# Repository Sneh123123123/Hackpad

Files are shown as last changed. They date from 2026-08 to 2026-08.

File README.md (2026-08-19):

# Hackpad / Macropad

A compact, USB-programmable custom hackpad using the Seeed Studio XIAO MCU. This device features a 4-button layout, a rotary potentiometer, an OLED graphic display and an audio module for tactile, multimedia, and automation control.

## Hardware Specifications

- **Microcontroller:** Seeed Studio XIAO (SAMD21)
- **Components:** 
  - 4 x Buttons
  - 1 x Rotary Potentiometer 
  - 1 x Audio Module
  - 1x OLED Graphic Display

## Core Features

- **Macropad Buttons:** 4 programmable buttons mapped to keyboard shortcuts, app launches, or dev tools (or whatever you want). 
- **Rotary Potentiometer:** Rotary potentiometer for smooth scrolling, volume control, or brush resizing.
- **Audio Module:** Audio module for status chimes, error beeps, or cool sound effects.
- **Pocket-Sized:** Minimalistic layout using the ultra-small Seeed Studio XIAO footprint.
- **OLED Graphic Display:** A Graphic Display for cool illustrations, animations and displays.

## Software & Firmware Setup

### Preparation
1. Download and install the [Arduino IDE](https://arduino.cc).
2. Add Seeed Studio boards to your IDE manager using the official guide.

### Installation
1. **Clone this repository:**
   (Yet to Add)
2. **Open the project:** Launch Arduino IDE and open `...`.
3. **Select Board:** Go to Tools > Board and select your specific Seeed Studio XIAO model.
4. **Upload:** Click the upload button to flash the firmware to your hackpad.

## Pin Configuration Reference

| Component | XIAO Pin | Description |
|:---|:---|:---|
| **Button 1** | D1 | (Yet to Add) |
| **Button 2** | D10 | (Yet to Add) |
| **Button 3** | D9 | (Yet to Add) |
| **Button 4** | D7 | (Yet to Add) |
| **Audio Module** | A2 (D2), A3 (D3), A8 (D8) | (Yet to Add)  |
| **Potentiometer** | D0 | (Yet to Add) |
|**OLED Graphic Display**| D4, D5| (Yet to Add)|

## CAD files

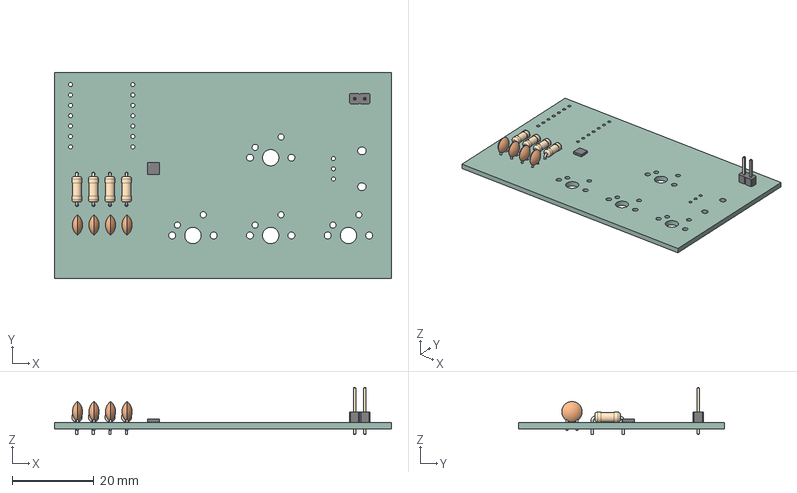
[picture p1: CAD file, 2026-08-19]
CAD Models/HackPad.step
82.5 x 50.5 x 11.5 mm
R_Axial_DIN0207_L63mm_D25mm_P762mm_Horizontal x 4
C_Disc_D50mm_W25mm_P250mm x 4
QFN-16-1EP_3x3mm_P0.5mm_EP1.7x1.7mm
PinHeader_1x02_P254mm_Vertical
HackPad-unsaved-export-QuULDD_PCB

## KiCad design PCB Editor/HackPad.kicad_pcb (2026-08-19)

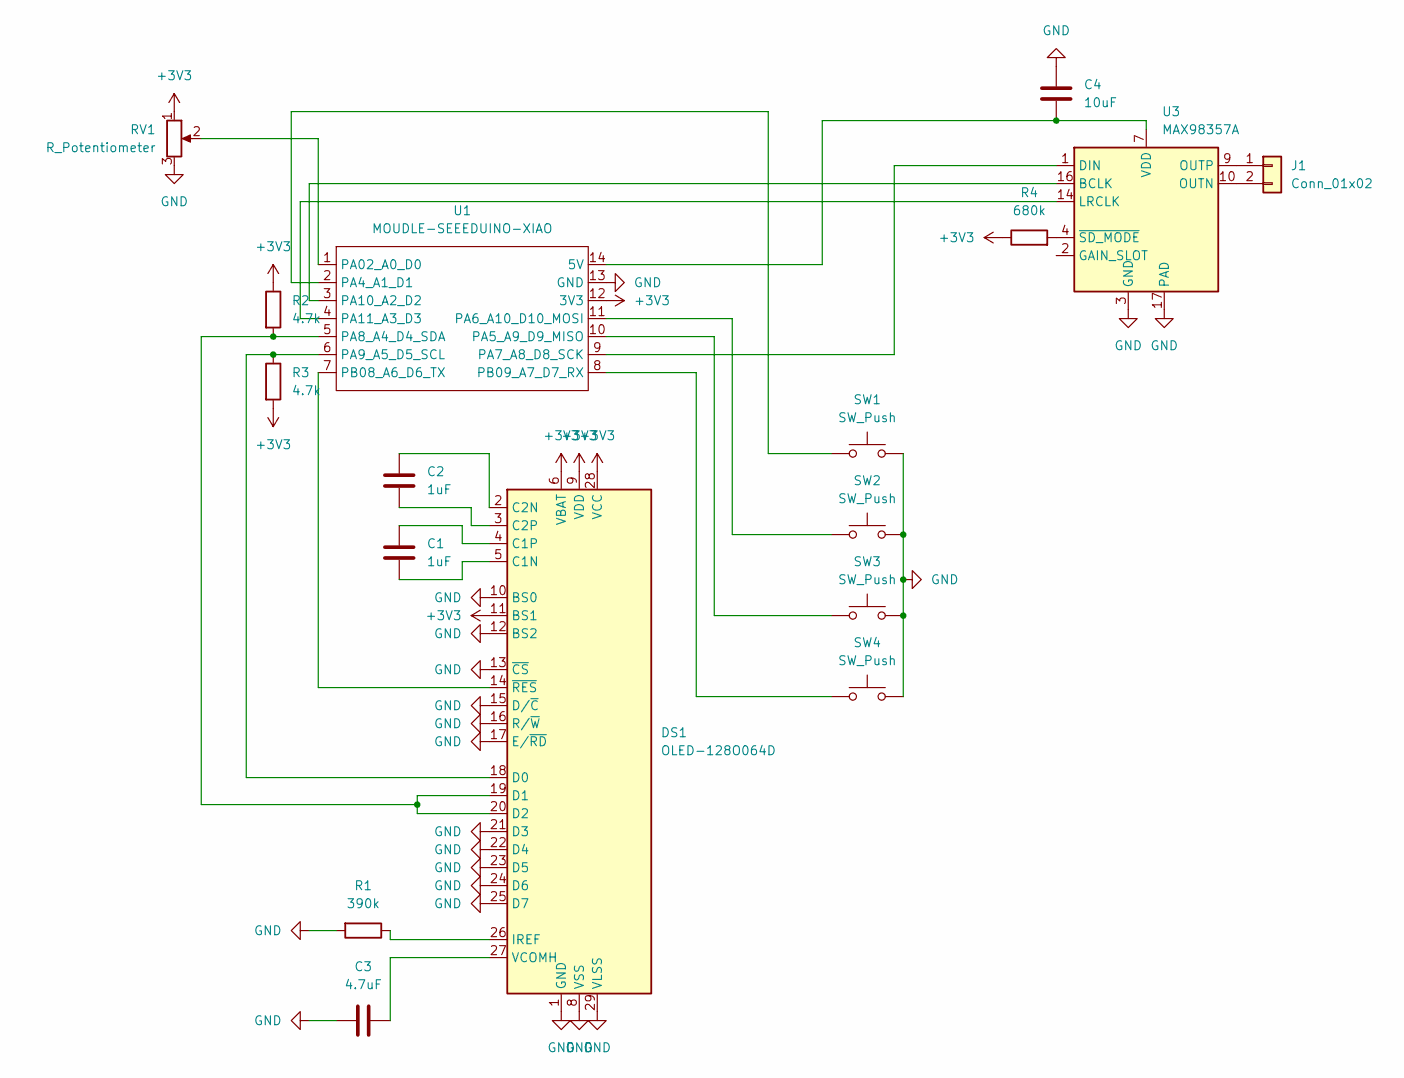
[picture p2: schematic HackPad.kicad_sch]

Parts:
C1, C2: 1uF; C_Disc_D5.0mm_W2.5mm_P2.50mm
C3: 4.7uF; C_Disc_D5.0mm_W2.5mm_P2.50mm
C4: 10uF; C_Disc_D5.0mm_W2.5mm_P2.50mm
DS1: OLED-128O064D
J1: Conn_01x02; PinHeader_1x02_P2.54mm_Vertical
R1: 390k; R_Axial_DIN0207_L6.3mm_D2.5mm_P7.62mm_Horizontal
R2, R3: 4.7k; R_Axial_DIN0207_L6.3mm_D2.5mm_P7.62mm_Horizontal
R4: 680k; R_Axial_DIN0207_L6.3mm_D2.5mm_P7.62mm_Horizontal
RV1: R_Potentiometer; Potentiometer_Alps_RK09K_Single_Vertical
SW1, SW2, SW3, SW4: SW_Push; SW_Cherry_MX_1.00u_PCB
U1: MOUDLE-SEEEDUINO-XIAO; XIAO-Generic-Hybrid-14P-2.54-21X17.8MM
U3: MAX98357A; QFN-16-1EP_3x3mm_P0.5mm_EP1.7x1.7mm

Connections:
+3V3: DS1.6 (VBAT), DS1.9 (VDD), DS1.11 (BS1), DS1.28 (VCC), R2.1, R3.2, R4.1, RV1.1, U1.12 (3V3)
GND: C3.2, C4.1, DS1.1 (GND), DS1.8 (VSS), DS1.10 (BS0), DS1.12 (BS2), DS1.13 (~CS), DS1.15 (D/~C), DS1.16 (R/~W), DS1.17 (E/~RD), DS1.21 (D3), DS1.22 (D4), DS1.23 (D5), DS1.24 (D6), DS1.25 (D7), DS1.29 (VLSS), DS1.30 (GND), R1.2, RV1.3, SW1.2, SW2.2, SW3.2, SW4.2, U1.13 (GND), U3.3 (GND), U3.11 (GND), U3.15 (GND), U3.17 (PAD)
unnamed: C1.2, DS1.5 (C1N)
unnamed: C1.1, DS1.4 (C1P)
unnamed: C2.1, DS1.2 (C2N)
unnamed: C2.2, DS1.3 (C2P)
unnamed: DS1.18 (D0), R3.1, U1.6 (PA9_A5_D5_SCL)
unnamed: DS1.19 (D1), DS1.20 (D2), R2.2, U1.5 (PA8_A4_D4_SDA)
unnamed: DS1.26 (IREF), R1.1
unnamed: C3.1, DS1.27 (VCOMH)
unnamed: DS1.14 (~RES), U1.7 (PB08_A6_D6_TX)
unnamed: J1.1, U3.9 (OUTP)
unnamed: J1.2, U3.10 (OUTN)
unnamed: C4.2, U1.14 (5V), U3.7 (VDD), U3.8 (VDD)
unnamed: RV1.2, U1.1 (PA02_A0_D0)
unnamed: SW1.1, U1.2 (PA4_A1_D1)
unnamed: SW3.1, U1.10 (PA5_A9_D9_MISO)
unnamed: SW2.1, U1.11 (PA6_A10_D10_MOSI)
unnamed: U1.9 (PA7_A8_D8_SCK), U3.1 (DIN)
unnamed: U1.3 (PA10_A2_D2), U3.16 (BCLK)
unnamed: U1.4 (PA11_A3_D3), U3.14 (LRCLK)
unnamed: SW4.1, U1.8 (PB09_A7_D7_RX)
unnamed: R4.2, U3.4 (~SD_MODE)

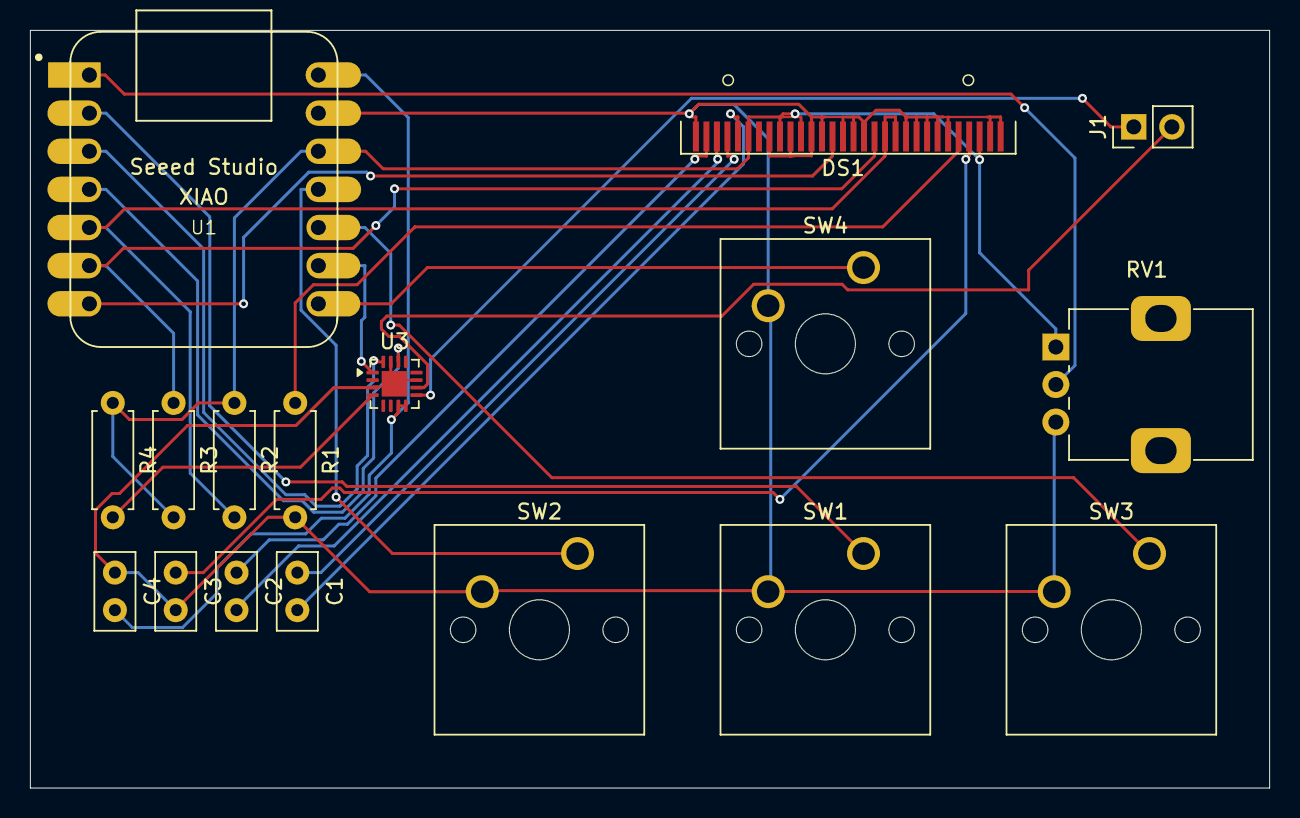
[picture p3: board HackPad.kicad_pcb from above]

Board: 2 copper layers, 82.5 x 50.5 mm, 17 parts (0 on the bottom side), 23 nets.
